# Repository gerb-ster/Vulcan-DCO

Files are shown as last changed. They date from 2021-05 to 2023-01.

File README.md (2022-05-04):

# Vulcan DCO

## Status: (Almost) finished*

- done: draw first schematic
- done: breadboard and test
- done: board design
- done: design frontpanel
- done: order PCB and build prototype

*) I only need to finish building a proper faceplate; otherwise this project is done.

## Theory

This DCO module is based on an article written by Alethea Flowers about the Roland Juno series. 
The idea behind this specific DCO is that a (analog) ramp generator is being controlled by 
a (digital) microcontroller. A clock signal comming from the micro controller will control the 
frequency of the ramp generator. The nature of this perticular circuit is such, that an increase of 
the frequency means an decrease of the output amplitude of the generated waveform. To counter 
this effect, a DAC is used to compensate the input voltage. If you want more in-depth information
about this, I would highly recommend you read the above mentioned article. A link is provided below.

## Requirements

For this module I aimed at the following specs

- 1v/oct control voltage (-3v to +5v)
- 8 octave range (A0 to A8)
- Triangle, Saw, Sine, Pulse, Square and Sub-Square outputs
- 1k output impedance
- 10 Vpp around 0 volts output
- PWM control for the Pulse output

## Internals

Since this systems requires a micro controller to control it, I've choosen the ATTiny84 running at 20Mhz
from Microchip for this purpose. It has all peripherals (ADC, timers, SPI) on board and it has a relative
small footprint. For the DAC I've choosen a MCP4921 which is connected to the ATTiny through SPI. To generate
a stabel reference voltage, a TL431 shunt voltage regulator is used. For all other tasks, scaling and shifting
the CV and wave generators, TL082/TL084 op-amps are used.

## General Workings

The control voltage comming in is scaled down by 2 and shifted down to 0v to translate the -3v/+5v into 0v/+4v.
Diode clamps are used to make sure the signal doesn't go below 0v or +5v. This signal is then fed to the 10bit 
ADC of the microchip, which has a AREF of 4v, so 0v has a value of 0, while 4v will have a value of 1024. This 
value is then used to determine the input voltage of the ramp genator using the DAC and the clock signal which 
controls it's frequency. The generated ramp wave is then used to generate the sine, triangle, and pulse waves
using several wave shapers. The square and sub square waves are taken directly from the clock signal comming 
from the microchip.

A simple block diagram outlining the inner workings

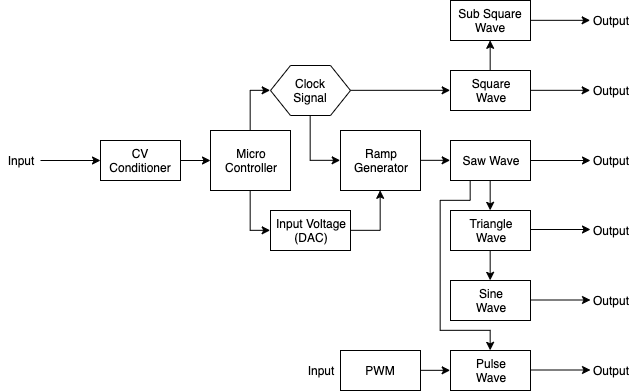
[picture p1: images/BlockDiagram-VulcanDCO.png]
Block Diagram


## The Microchip

The most interresting part of this system is the microchip controlling the ramp generator. All other parts are
more or less standard building blocks which you will find in various other VCO schematics. As mentioned above,
the microchip uses it's ADC to convert the incoming control voltage to a 10bit value which is used to control
the ramp generator. To do this, every one of these 1024 values needs to be translated to a certain clock 
frequency and an input voltage. Since this is not a linear scale, some math has to be done. I've tried to break
it down in the following sections:

### CV to Frequencies

I've used this table to translate the control voltages to frequencies. I've also added the CV value after shifting
and scaling and the correspondending ADC values. 

| CV | Norm. CV | Note | Hz | ADC Value  |
|---|---|---|---|---|
| -3v | 0.0v | A0 | 27.5 Hz | 0
| -2v | 0.5v | A1 | 55 Hz | 127
| -1v | 1.0v | A2 |  110 Hz | 255
| 0v | 1.5v | A3 |  220 Hz | 383
| 1v | 2.0v | A4 |  440 Hz | 511
| 2v | 2.5v | A5 |  880 Hz | 639
| 3v | 3.0v | A6 | 1760 Hz | 767
| 4v | 3.5v | A7 | 3520 Hz | 895
| 5v | 4.0v | A8 | 7040 Hz | 1023

The formula used here is:

```
frequency = (2 ^ (2 * normalized_control_voltage)) * 27.5
```

### Setting the Clock Frequency

For the clock signal I've used one of the Timers (timer1) of the ATTiny84. It is set up in such a
way that it generates a square wave at pin 7 with a frequency set by manipulating a compare mode
value. If you want more specifics and want to know what registers are set, please check out the 
source code, comments are provided. For every duty cycle of the squeare wave we need 2 pulses, one
to turn the output high, one to turn it low. This formula is used ('F_CPU' is the clock speed of the
CPU (20Mhz) and 'current_prescaler' is the prescaler used in this timer(8)):

```
timer_value = (F_CPU / current_prescaler) / (frequency * 2)
```

For more information about using the timer of an ATTiny84, links are provided below.

### Input Voltage Compensation

As mentioned above, we need to compensate the input voltage of the ramp generator to make sure the
amplitude of the output remains the same. To do this we use a DAC. The DAC generates a voltage between
0v and 4v, using a 12bit value (0-4096). For this we also use the 4.00v shunt voltage regulator as a
voltage reference. This voltage is then inverted and multiplied with a factor 3 to cover a range of
0v to -12v. This way the ramp generator will output a 12vpp ramp between 0v and 12v.

The formula to transform a frequency to the appropriate DAC voltage can be found in the article by
Alethea Flowers, she explains it in much better details then I can do, so if you're interested in that,
the link can be found below.

```
C = 1nF
R = 200k Ohm
Vout = +12v

time = 1 / frequency
Vin = -(C * R * Vout) / time
```

#### However... 

After a lot of testing and doing measurements I found out that this formula works, but it kind of 
starts failing for the lower frequencies. Below 300Hz you will need a higher input voltage to get a consistent
output voltage. To make it easier for myself I've picked an 10Vpp instead of 12Vpp for my measurements. I've
plotted these numbers on a graph and it turned out pretty linear so when i used the formula which came out
this graph, the low end output voltage are much more consistent.

I'm not a mathematician so why or how this formula works, i don't know :-)

```
Vin = (0.697151065 * frequency) + 40.82
```

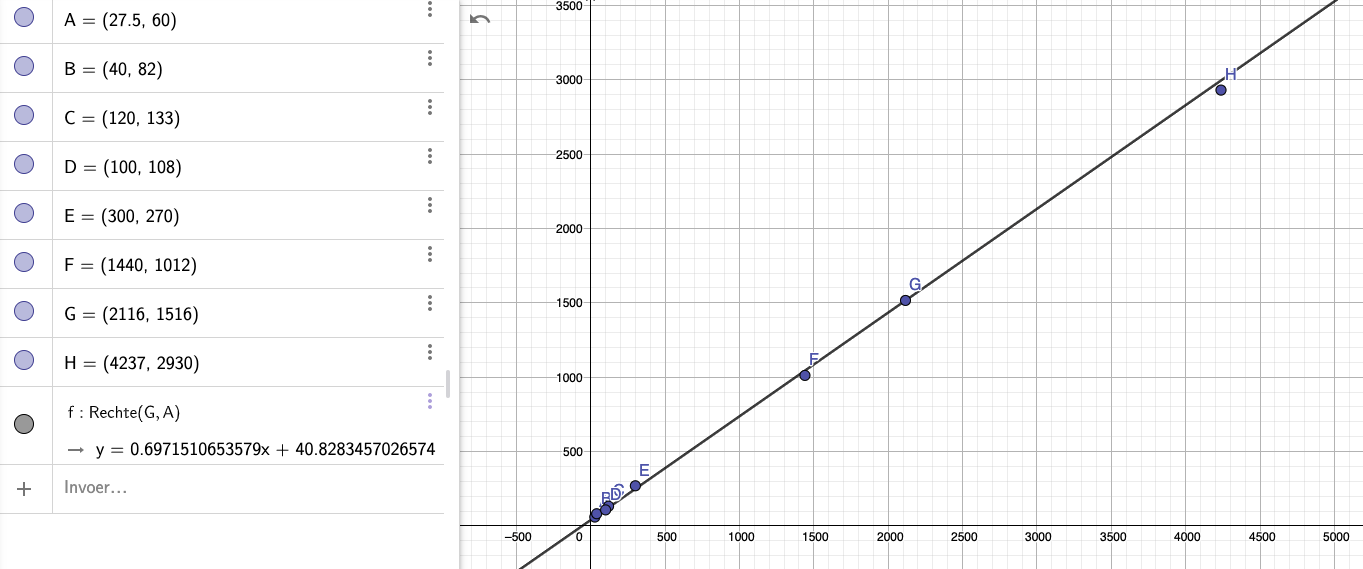
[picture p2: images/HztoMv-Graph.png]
Hz to mV Graph


### Lookup Tables

If you look through the source code you won't find any of the above decribed formulas. This is because 
I've used 2 lookup tables to speed things up. Although the ATTiny84 could do the Math involved, this is 
not really necessary. Every one of the 1024 values coming from ADC will translate into a 'fixed' timer and 
DAC value. So there is no real need to calculate these values on the fly. These lookup tables are basically 
2 giant arrays, 1024 elements in size, which contain all pre-calculated values. These arrays are stored in
the Flash memory of the ATTiny since the normal RAM is to small. 

In the 'utils' folder you can find the ```generator.php``` file which is used to generate those tables and 
code. I've choosen to use PHP for this, because this is my 'native' language :-).

## Waveshapers

The Square and Sub-Square outputs are derived directly from the Clock signal using various op-amps and a 
CD4013 Dual Flip-Flop IC. This schematic is taken from a design for the 'making music with a 566' by
Thomas Henry. Next, the Saw Wave coming out of the Ramp generator is used to shape it into a Triangle wave.
This Triangle wave is then used to generate a Sine wave. The Saw wave is also used to create a Pulse wave.
There is a CV input and pot to control the Pulse Width Modulation. For these wave shapers I've used 
designs from Thomas Henry, Ray Wilson and Yves Usson (YUSynth). Links are found below.

## Calibration

There are 2 trimmerpots that need to be set, in order to calibrate the Ramp Generator Core. 

CV_OFFSET => -1.5v  
VREF_SET => 4.00v  

## Links

<https://blog.thea.codes/the-design-of-the-juno-dco/>  
<https://www.geogebra.org/graphing/mfdyqrfj>  
<https://www.bristolwatch.com/ccs/TL431A.htm>  
<https://github.com/JChristensen/tinySPI>  
<https://github.com/MetreIdeas/ATtinyx4A_ADC_Example>  
<https://eleccelerator.com/avr-timer-calculator/>  
<https://maxembedded.wordpress.com/2011/06/28/avr-timers-timer1/>  
<https://www.nongnu.org/avr-libc/user-manual/pgmspace.html>  
<https://www.arduino.cc/reference/tr/language/variables/utilities/progmem/>  
<https://www.birthofasynth.com/Thomas_Henry/Pages/VCO-1.html>  
<https://yusynth.net/Modular/EN/VCO/index.html>

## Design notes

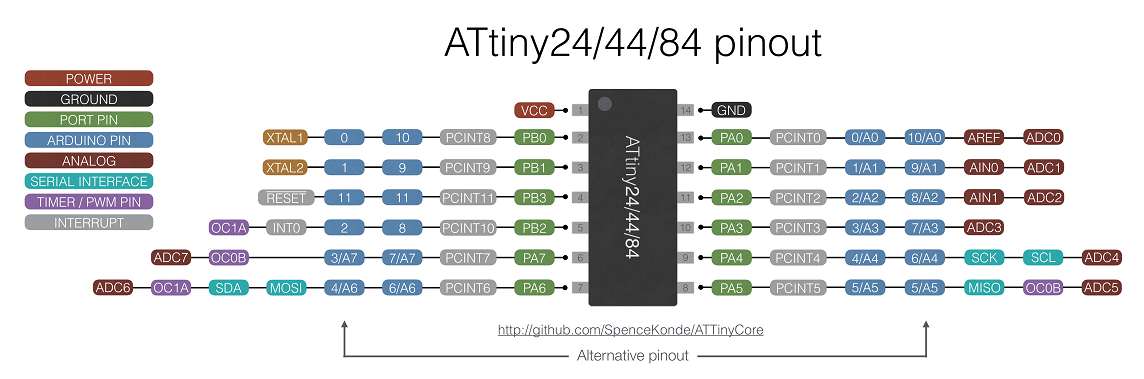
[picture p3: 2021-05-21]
images/attiny-pinout-diagram.png

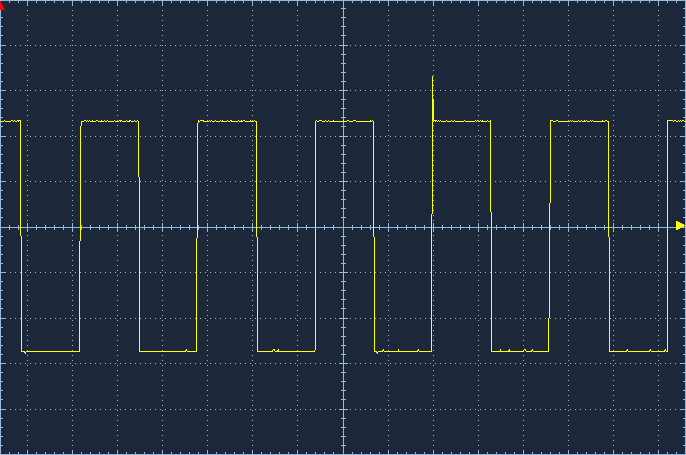
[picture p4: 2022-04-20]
images/square.png

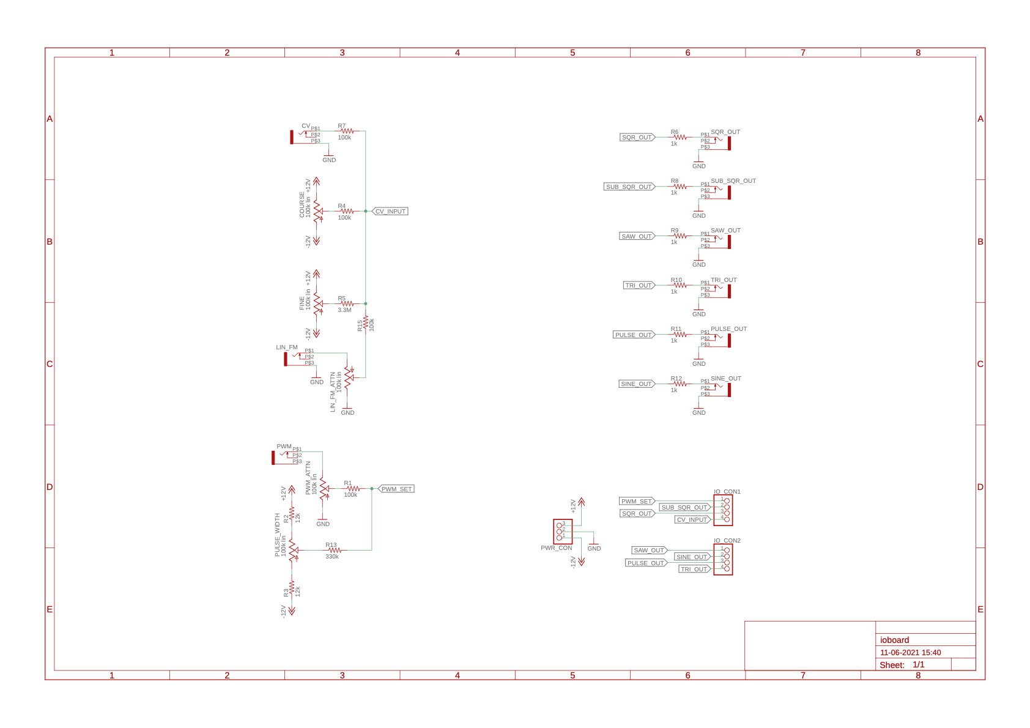
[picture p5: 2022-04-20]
images/Vulcan-DCO-ioboard.png

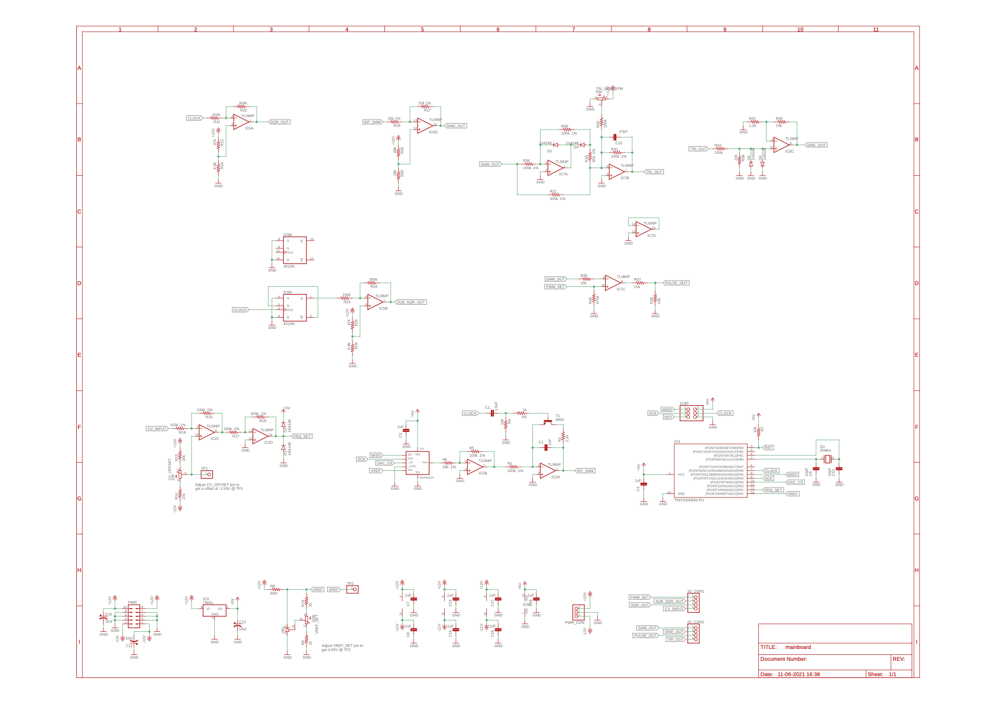
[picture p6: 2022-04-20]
images/Vulcan-DCO-mainboard.png

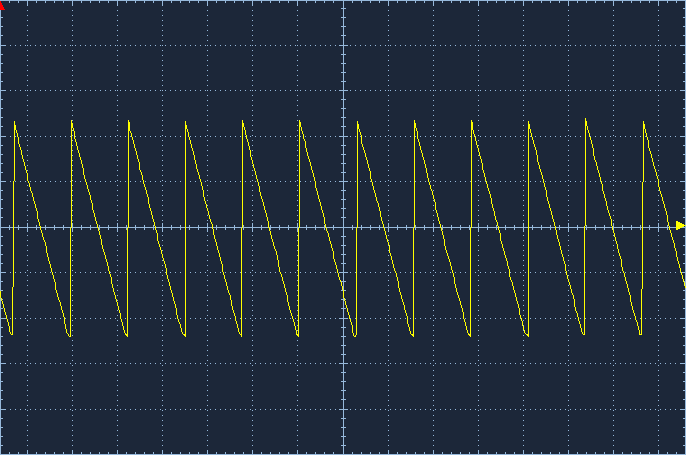
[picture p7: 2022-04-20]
images/saw.png

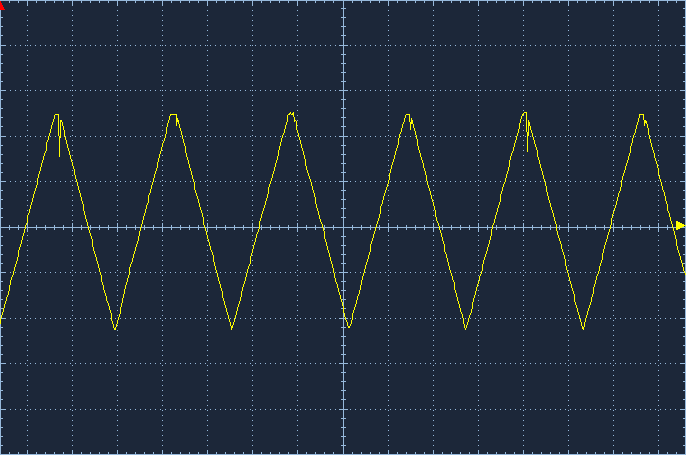
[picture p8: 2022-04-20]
images/triangle.bmp

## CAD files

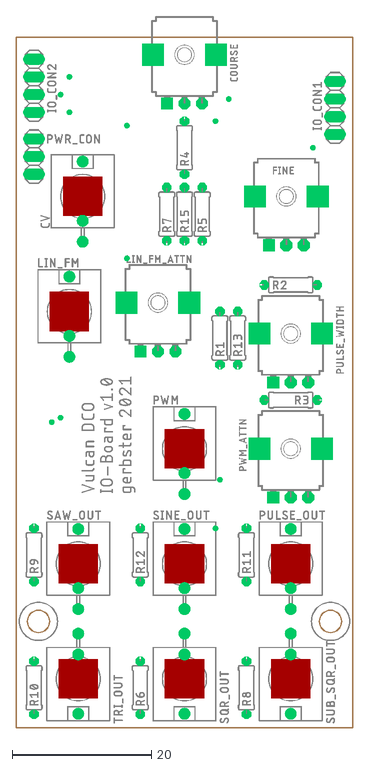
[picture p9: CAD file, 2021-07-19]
faceplates/ioboard.dxf
48.3 x 102.0

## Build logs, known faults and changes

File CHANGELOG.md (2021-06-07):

# Changelog

All notable changes to this project will be documented in this file.

The format is based on [Keep a Changelog](https://keepachangelog.com/en/1.0.0/),
and this project adheres to [Semantic Versioning](https://semver.org/spec/v2.0.0.html).

## [1.0.0] - 2021-21-05

### Added

- Inintial repo setup
- First version of firmware added

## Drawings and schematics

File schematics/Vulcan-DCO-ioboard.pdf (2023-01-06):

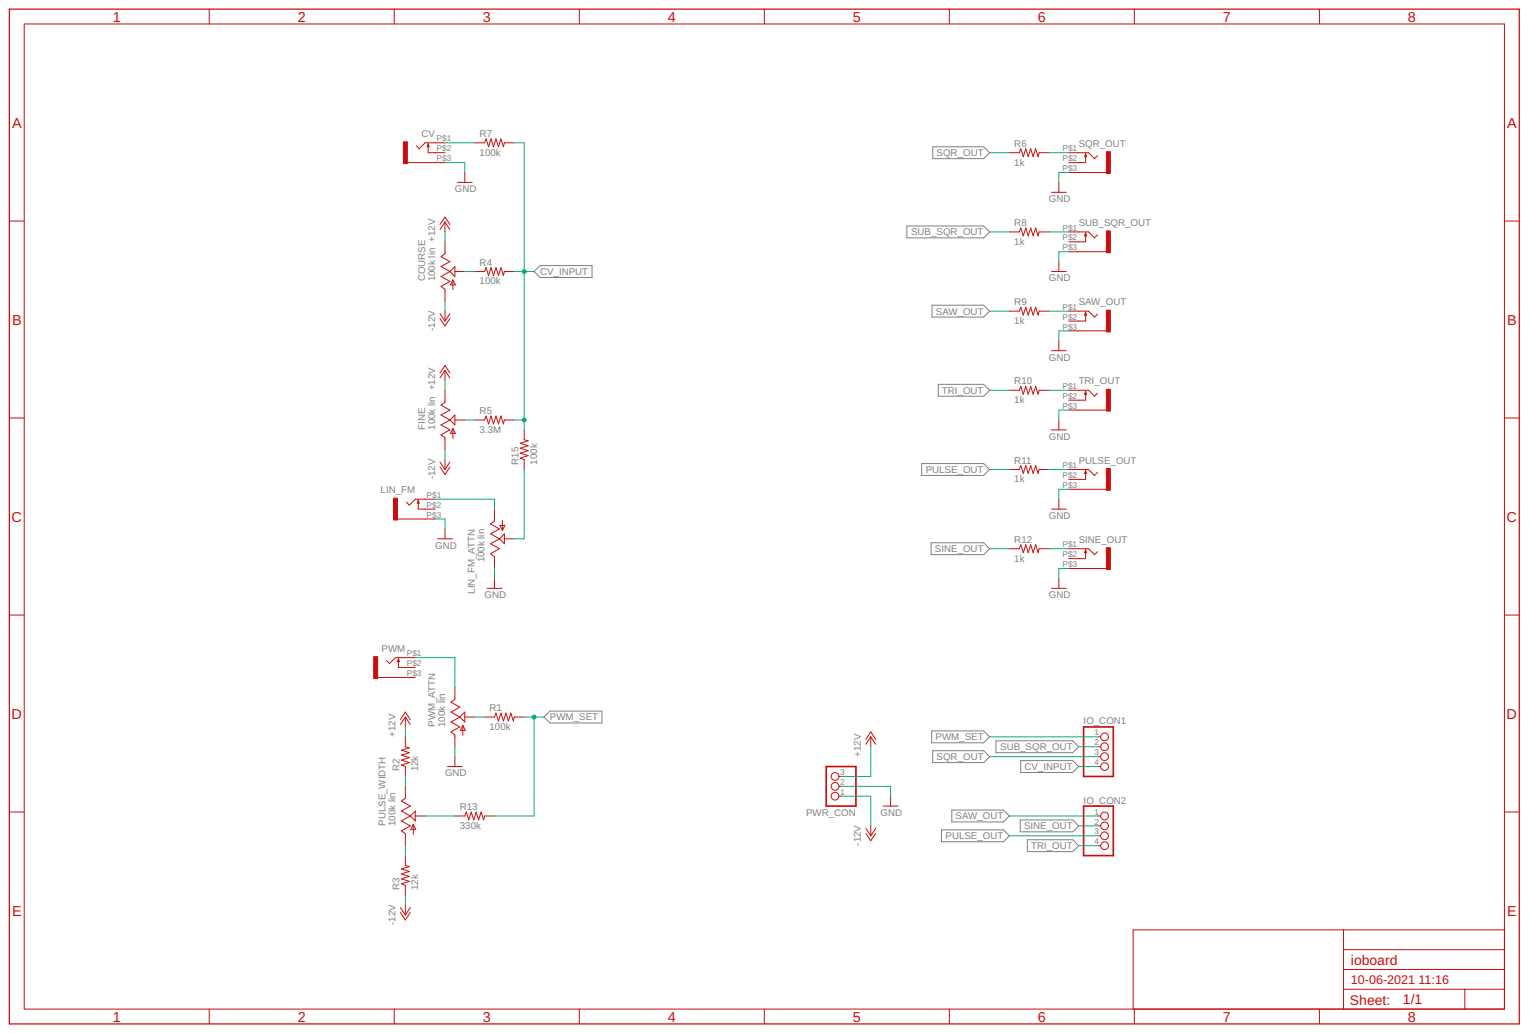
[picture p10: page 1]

+12V -12V GND 100k lin 100k lin 100k lin +12V -12V -12V +12V 100k 3.3M 1k GND 100k 1k1k1k1k GND GND GND GND GND GND +12V -12V 330k 100k lin GND GND 100k 100k lin GND 100k 12k 12k 1k 123 PWR_CON COURSE FINE PULSE_WIDTH R4 R5 R6 P$3 P$1 P$2 CV P$3 P$1 P$2 PWM P$3 P$1 P$2SQR_OUT P$3 P$1 P$2SUB_SQR_OUT P$3 P$1 P$2SAW_OUT P$3 P$1 P$2TRI_OUT P$3 P$1 P$2PULSE_OUT P$3 P$1 P$2SINE_OUT R7 R8 R9 R10 R12 R13 P$3 P$1 P$2 LIN_FM LIN_FM_ATTN R15 PWM_ATTN R1 R2 R3 R11 1234 IO_CON2 1234 IO_CON1 CV_INPUT CV_INPUT SQR_OUT SQR_OUT SUB_SQR_OUT SUB_SQR_OUT SAW_OUT SAW_OUT TRI_OUT TRI_OUT PULSE_OUT PULSE_OUT SINE_OUT SINE_OUT PWM_SET PWM_SET Sheet: ABCDE 1 2 3 4 5 6 7 8 ABCDE 1 2 3 4 5 6 7 8 ioboard 10-06-2021 11:16 1/1

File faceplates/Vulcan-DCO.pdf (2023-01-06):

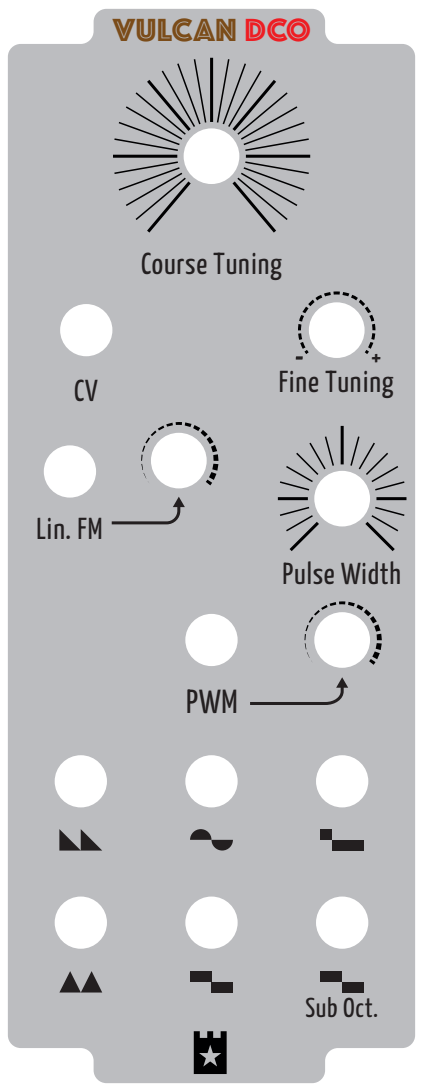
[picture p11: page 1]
Course Tuning; Lin. FM; Pulse Width; PWM; VULCAN DCO; Sub Oct.

Fine Tuning CV

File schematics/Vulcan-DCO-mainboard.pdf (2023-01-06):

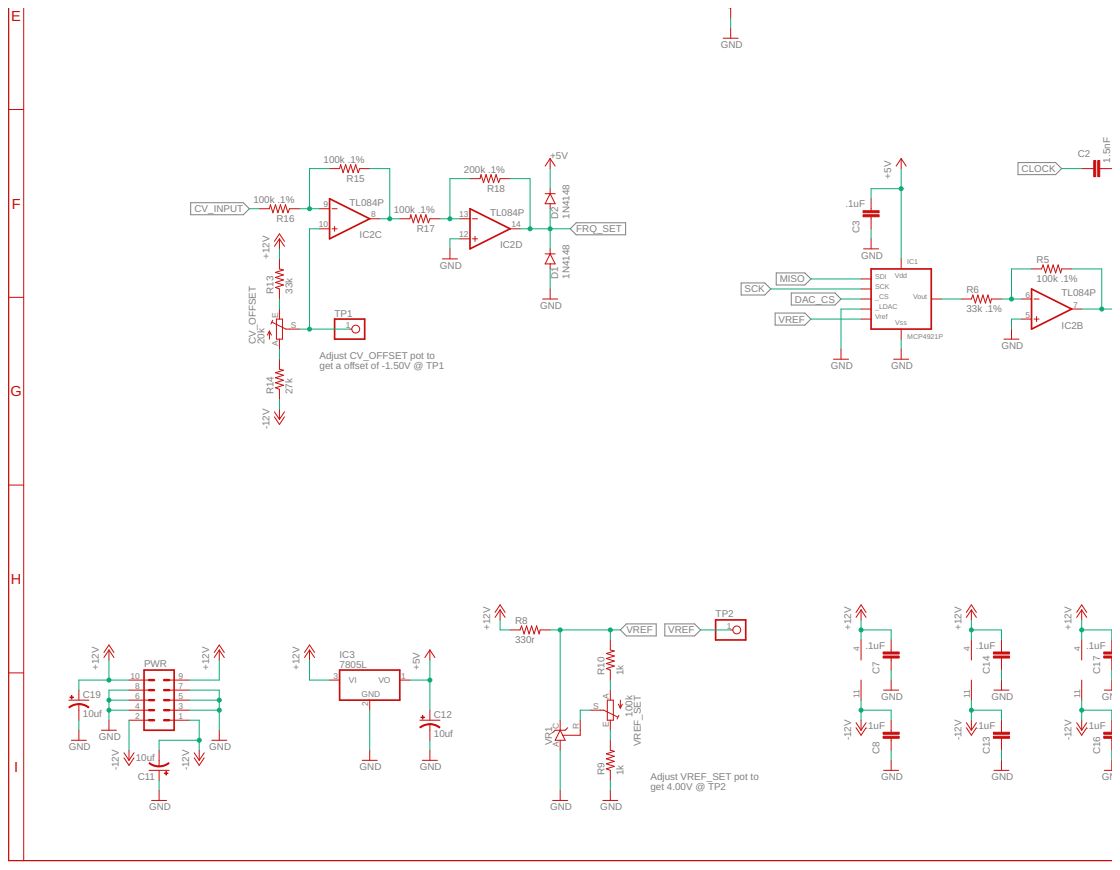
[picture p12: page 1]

Vdd Vss Vout Vref SCK

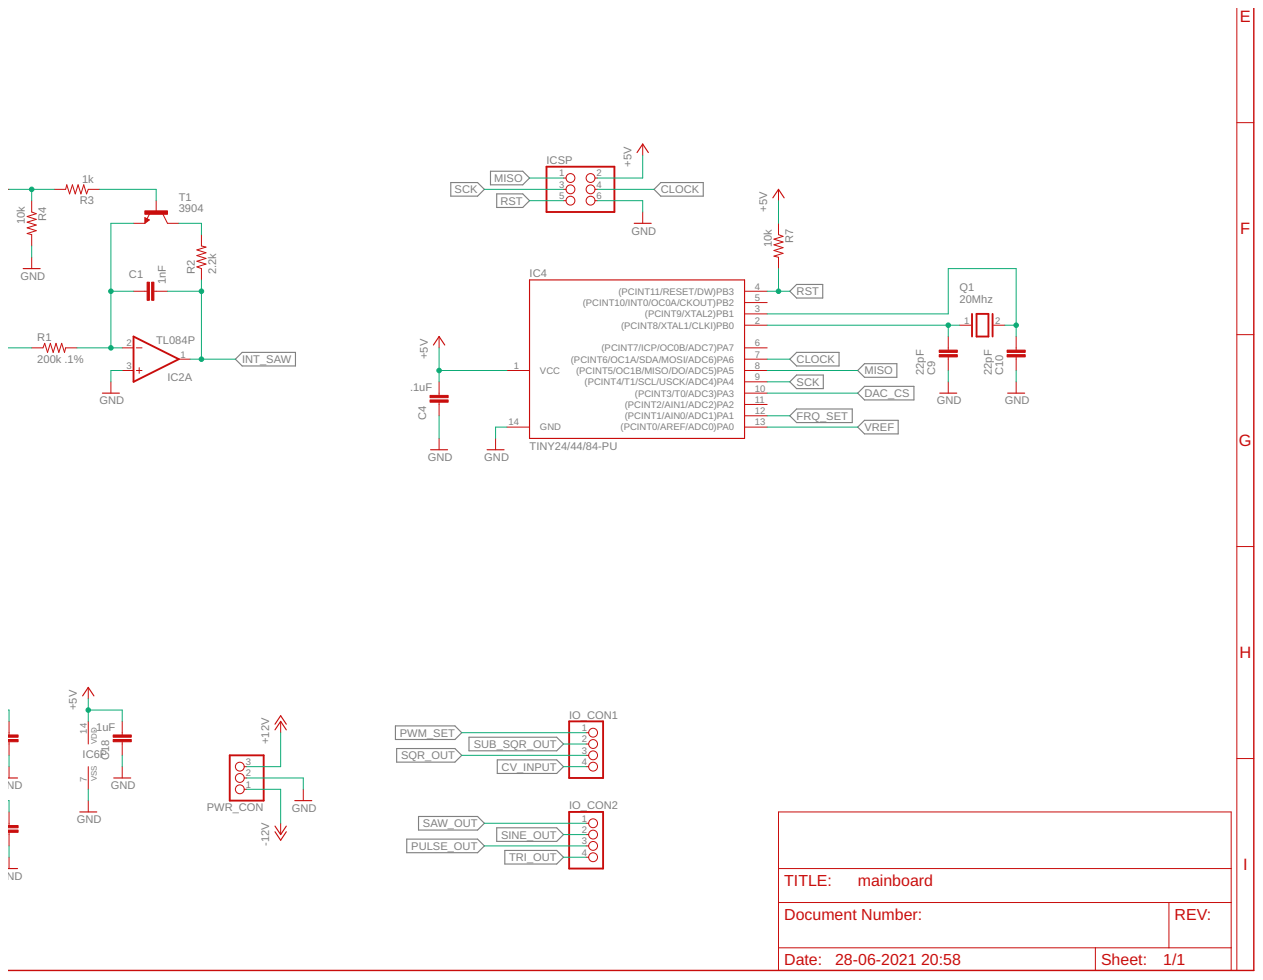
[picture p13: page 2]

Document Number: | REV:

Date: 28-06-2021 20:58 | Sheet: 1/1

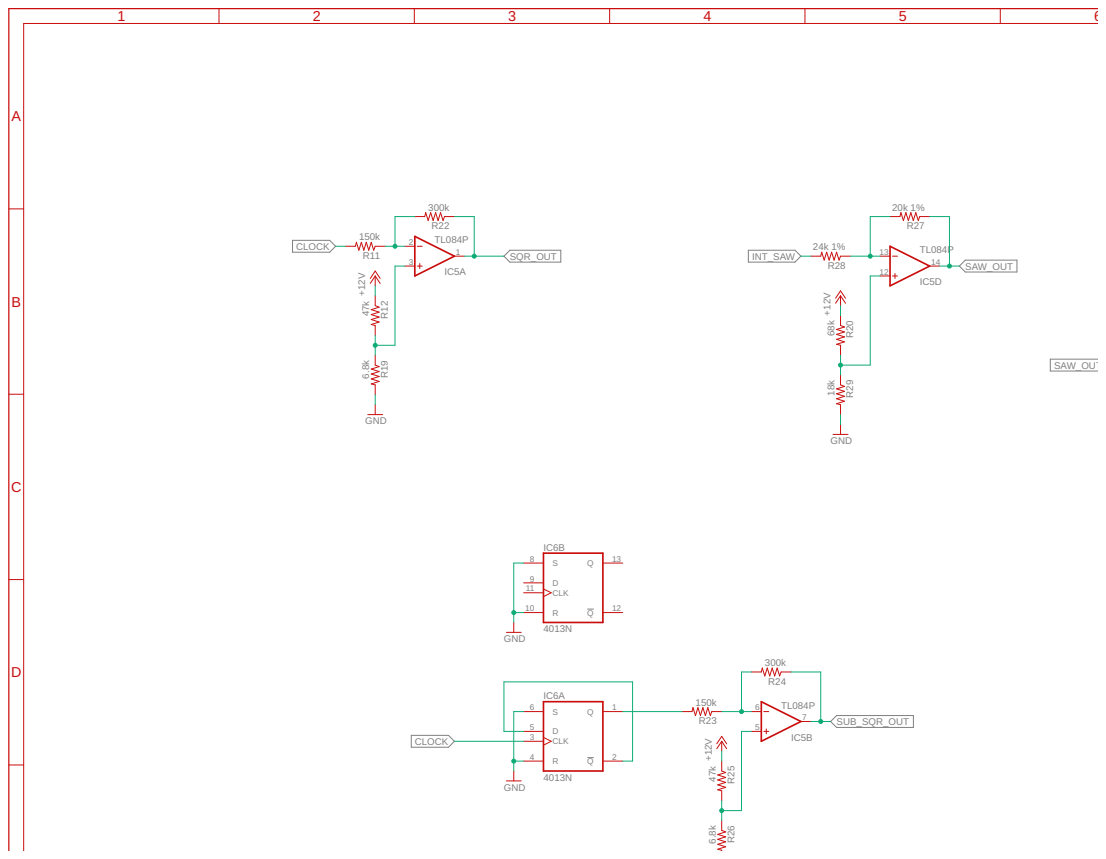
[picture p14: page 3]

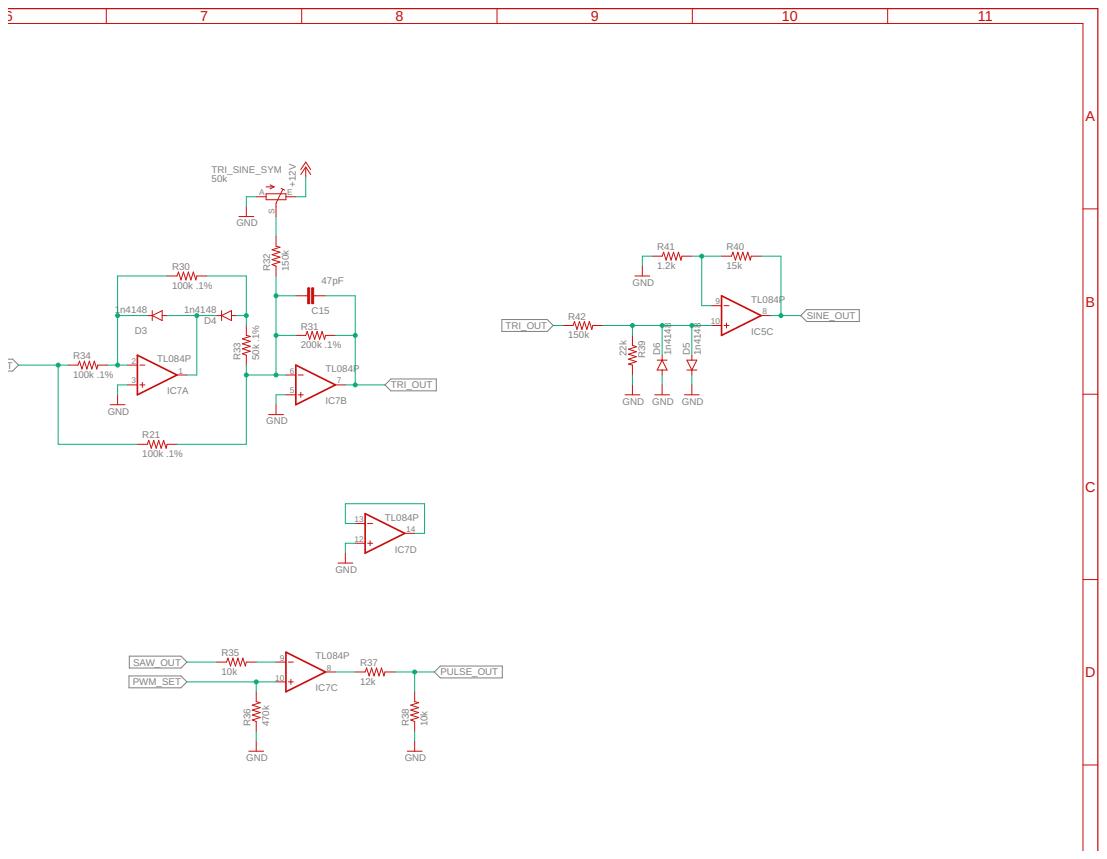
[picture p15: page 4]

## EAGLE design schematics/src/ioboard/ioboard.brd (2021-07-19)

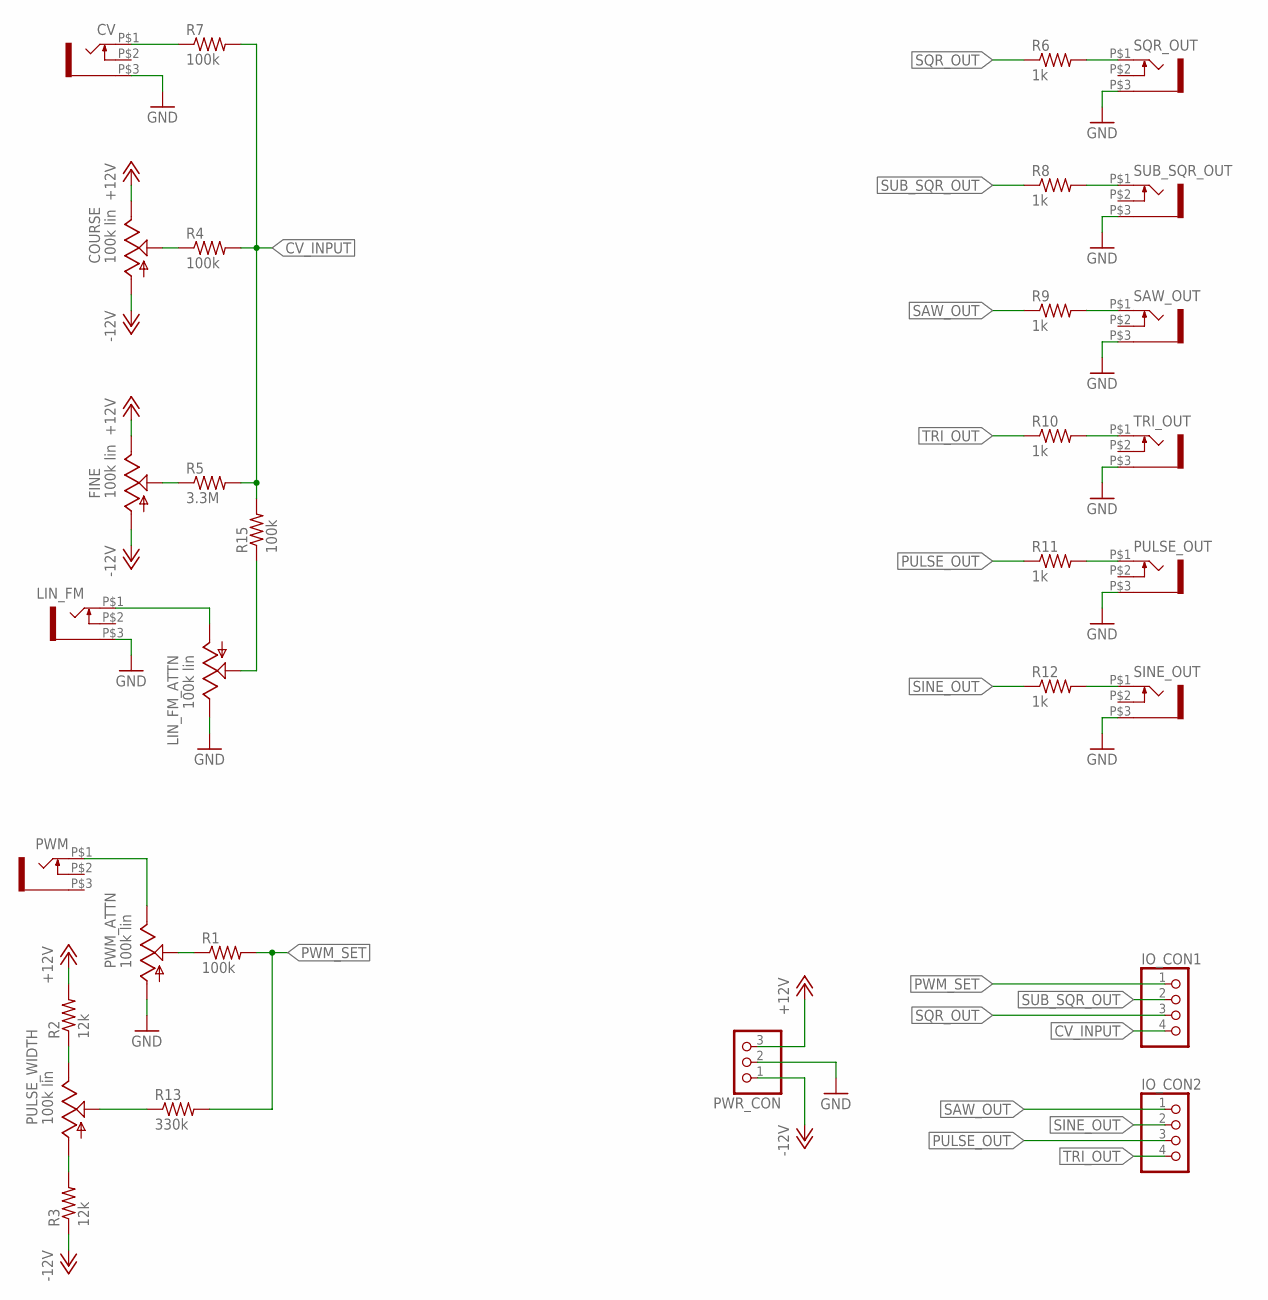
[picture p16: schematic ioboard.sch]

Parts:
COURSE: 100k lin; EVUF
CV: WQP-PJ301M-12_JACK
FINE: 100k lin; EVUF
IO_CON1, IO_CON2: PINHD-1X4; 1X04
LIN_FM: WQP-PJ301M-12_JACK
LIN_FM_ATTN: 100k lin; EVUF
PULSE_OUT: WQP-PJ301M-12_JACK
PULSE_WIDTH: 100k lin; EVUF
PWM: WQP-PJ301M-12_JACK
PWM_ATTN: 100k lin; EVUF
PWR_CON: PINHD-1X3; 1X03
R1, R4, R7, R15: 100k; 0207/7
R2, R3: 12k; 0207/7
R5: 3.3M; 0207/7
R6, R8, R9, R10, R11, R12: 1k; 0207/7
R13: 330k; 0207/7
SAW_OUT: WQP-PJ301M-12_JACK
SINE_OUT: WQP-PJ301M-12_JACK
SQR_OUT: WQP-PJ301M-12_JACK
SUB_SQR_OUT: WQP-PJ301M-12_JACK
TRI_OUT: WQP-PJ301M-12_JACK

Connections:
+12V: COURSE.3 (E), FINE.3 (E), PWR_CON.3, R2.2
-12V: COURSE.1 (A), FINE.1 (A), PWR_CON.1, R3.1
CV_INPUT: IO_CON1.4, R4.2, R5.2, R7.2, R15.2
GND: CV.P$3 (1), LIN_FM.P$3 (1), LIN_FM_ATTN.3 (E), PULSE_OUT.P$3 (1), PWM_ATTN.1 (A), PWR_CON.2, SAW_OUT.P$3 (1), SINE_OUT.P$3 (1), SQR_OUT.P$3 (1), SUB_SQR_OUT.P$3 (1), TRI_OUT.P$3 (1)
unnamed: COURSE.2 (S), R4.1
unnamed: FINE.2 (S), R5.1
unnamed: PULSE_WIDTH.3 (E), R2.1
unnamed: CV.P$1 (2), R7.1
unnamed: R6.2, SQR_OUT.P$1 (2)
unnamed: R8.2, SUB_SQR_OUT.P$1 (2)
unnamed: R9.2, SAW_OUT.P$1 (2)
unnamed: R10.2, TRI_OUT.P$1 (2)
unnamed: PULSE_WIDTH.1 (A), R3.2
unnamed: R12.2, SINE_OUT.P$1 (2)
unnamed: PULSE_WIDTH.2 (S), R13.1
unnamed: PWM.P$1 (2), PWM_ATTN.3 (E)
unnamed: PULSE_OUT.P$1 (2), R11.2
unnamed: PWM_ATTN.2 (S), R1.1
unnamed: LIN_FM.P$1 (2), LIN_FM_ATTN.1 (A)
unnamed: LIN_FM_ATTN.2 (S), R15.1
PULSE_OUT: IO_CON2.3, R11.1
PWM_SET: IO_CON1.1, R1.2, R13.2
SAW_OUT: IO_CON2.1, R9.1
SINE_OUT: IO_CON2.2, R12.1
SQR_OUT: IO_CON1.3, R6.1
SUB_SQR_OUT: IO_CON1.2, R8.1
TRI_OUT: IO_CON2.4, R10.1

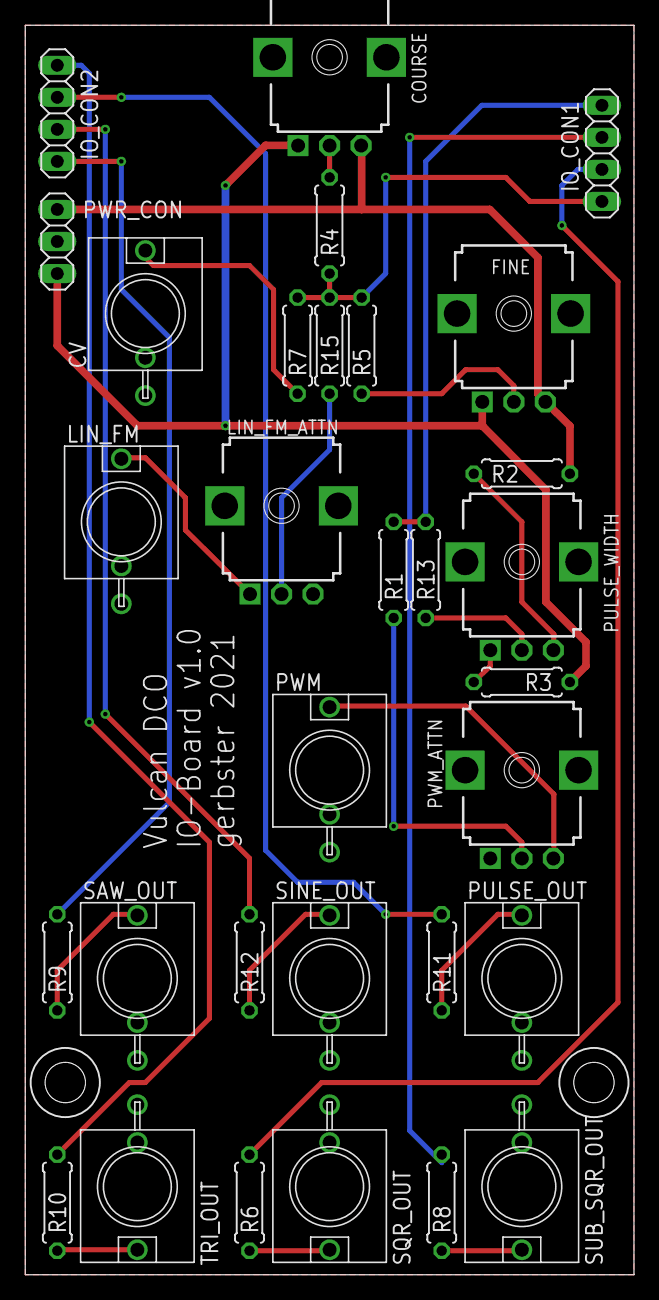
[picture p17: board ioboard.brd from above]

Board: 2 copper layers, 48.3 x 99.1 mm, 31 parts (0 on the bottom side), 27 nets.

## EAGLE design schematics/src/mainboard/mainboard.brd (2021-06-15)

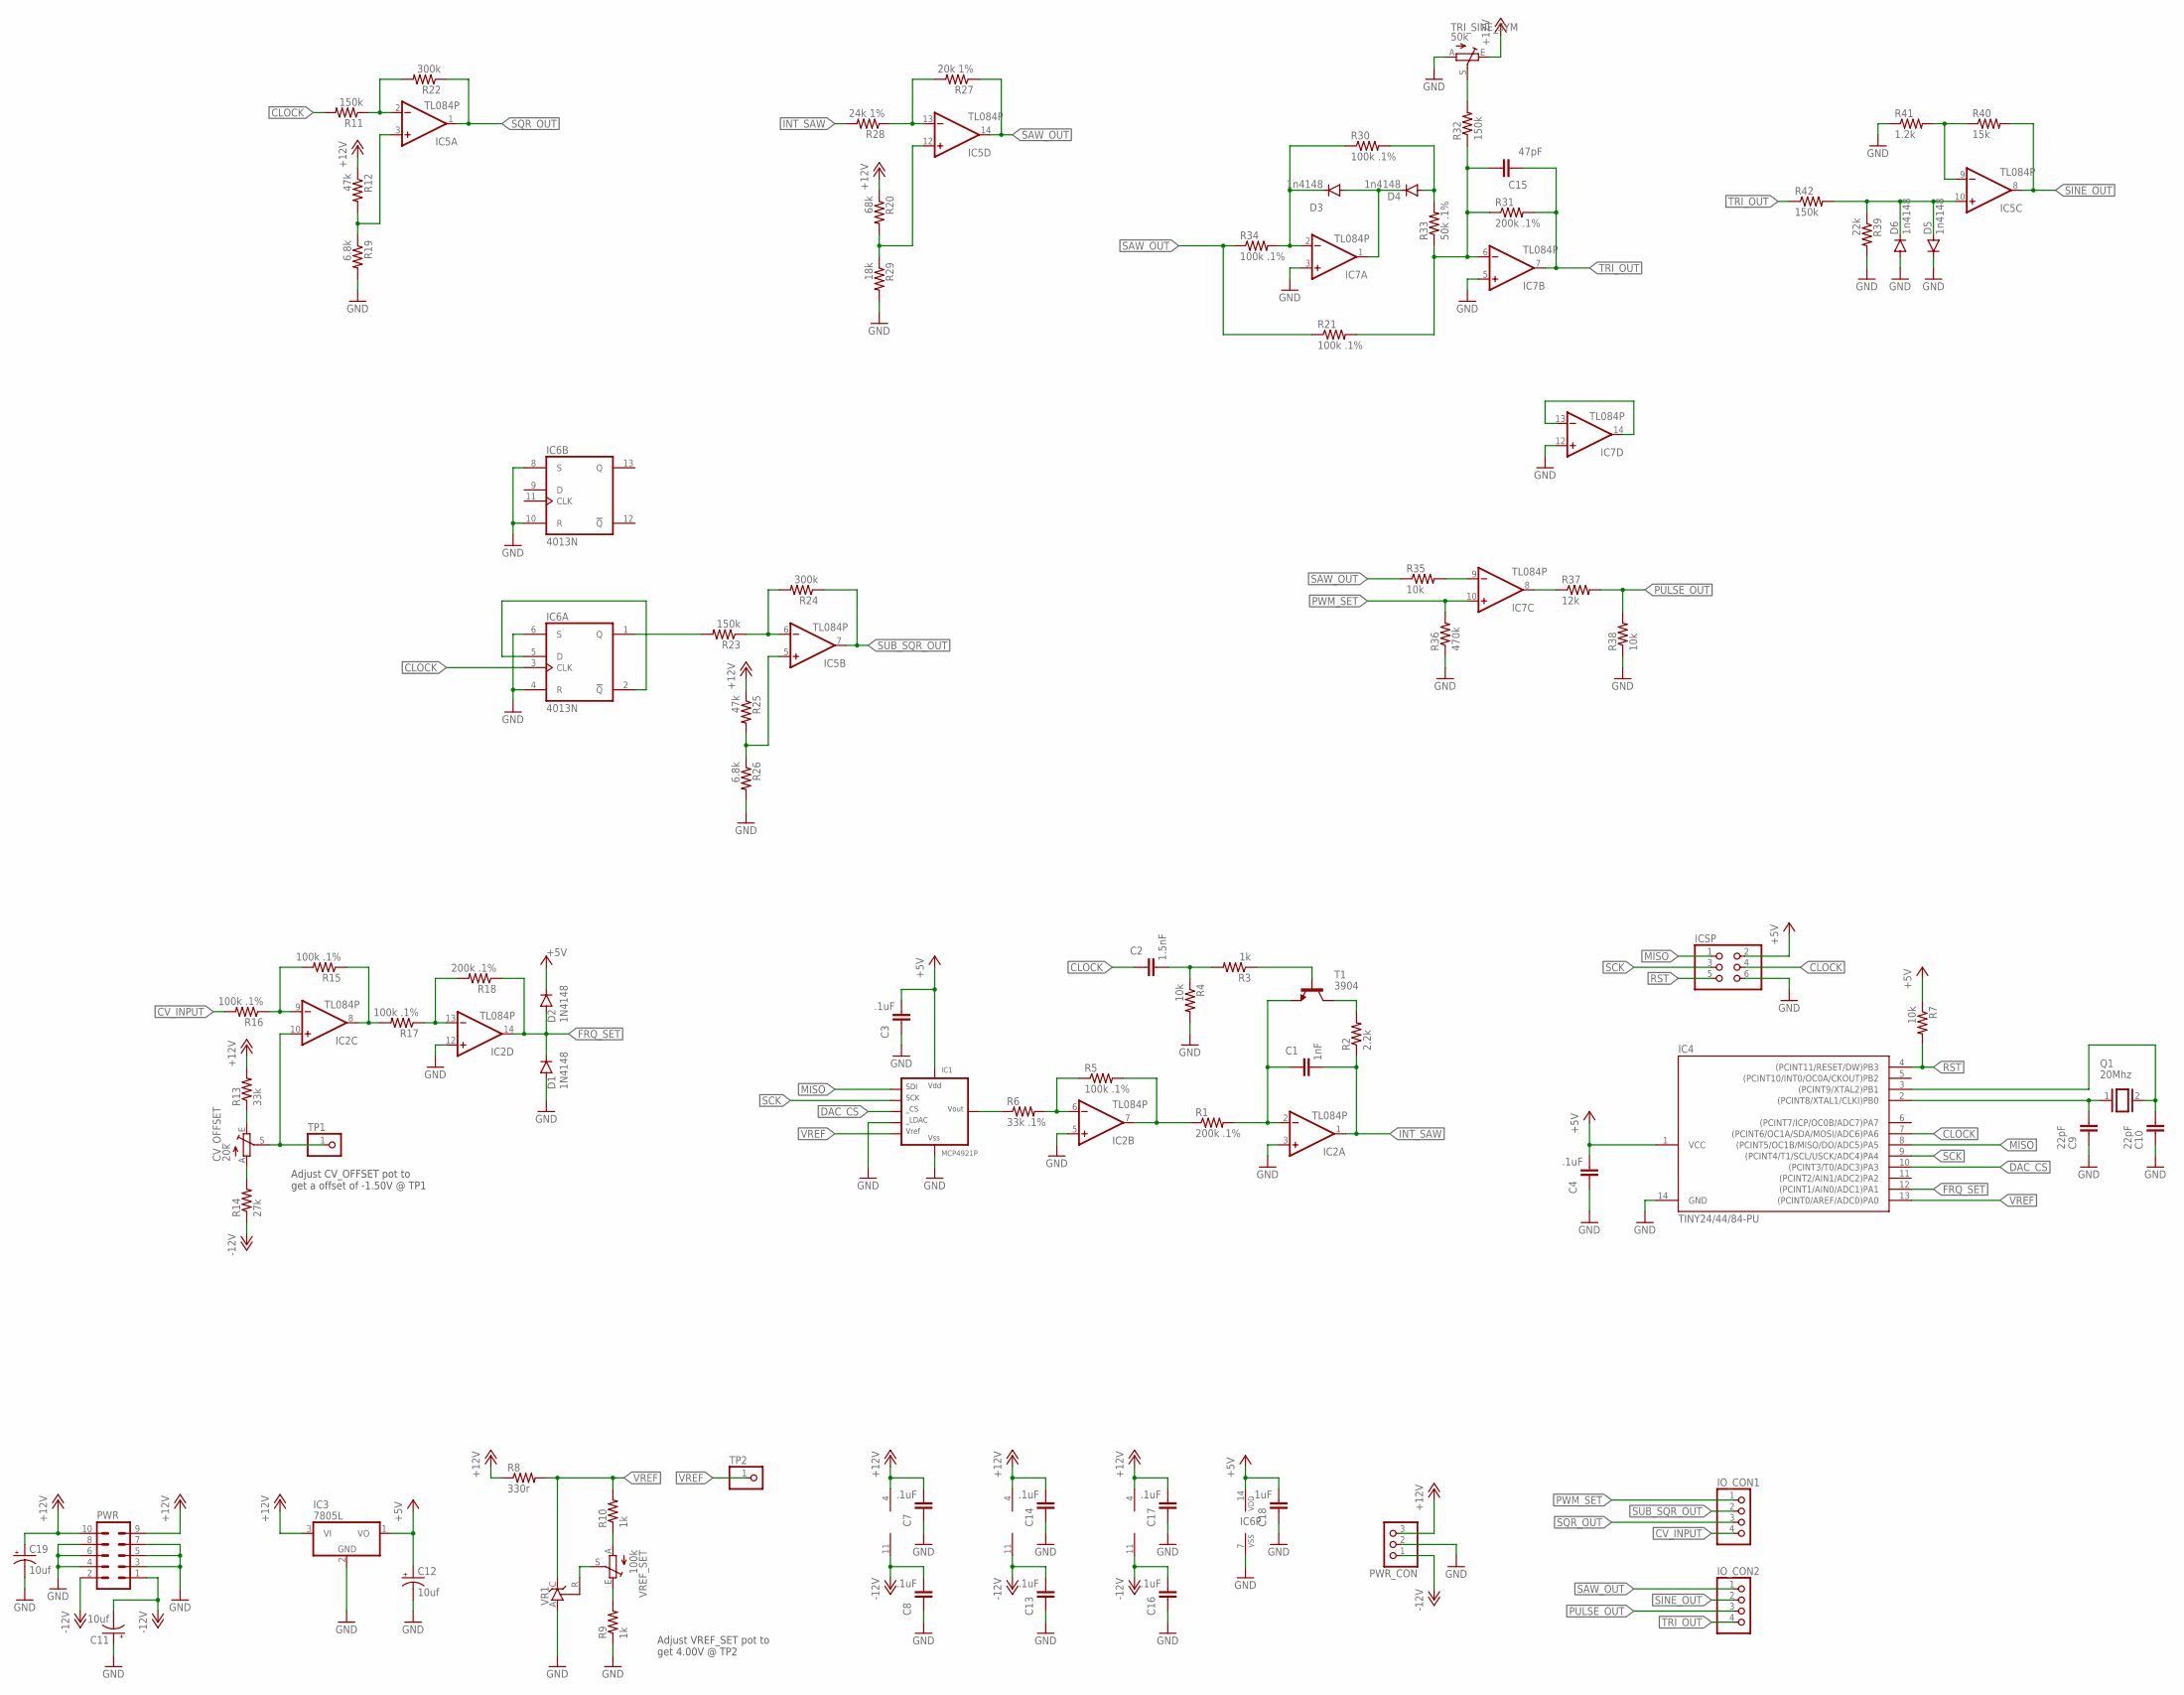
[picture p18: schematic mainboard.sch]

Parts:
C1: 1nF; C050-025X075
C2: 1.5nF; C050-024X044
C3, C4, C7, C8, C13, C14, C16, C17, C18: .1uF; C050-024X044
C9, C10: 22pF; C050-024X044
C11, C12, C19: 10uf; E2,5-5
C15: 47pF; C050-024X044
CV_OFFSET: 20k; S64YW
D1, D2: 1N4148; DO35-7
D3, D4, D5, D6: 1n4148; DO35-7
IC1: MCP4921P; DIL8
IC2, IC5, IC7: TL084P; DIL14
IC3: 7805L; TO92
IC4: TINY24/44/84-PU; DIL14
IC6: 4013N; DIL14
ICSP: PINHD-2X3; 2X03
IO_CON1, IO_CON2: PINHD-1X4; 1X04
PWR: ML10
PWR_CON: PINHD-1X3; 1X03
Q1: 20Mhz; QS
R1, R18, R31: 200k .1%; 0207/7
R2: 2.2k; 0207/7
R3, R9, R10: 1k; 0207/7
R4, R7, R35, R38: 10k; 0207/7
R5, R15, R16, R17, R21, R30, R34: 100k .1%; 0207/7
R6: 33k .1%; 0207/7
R8: 330r; 0207/7
R11, R23, R32, R42: 150k; 0207/7
R12, R25: 47k; 0207/7
R13: 33k; 0207/7
R14: 27k; 0207/7
R19, R26: 6.8k; 0207/7
R20: 68k; 0207/7
R22, R24: 300k; 0207/7
R27: 20k 1%; 0207/7
R28: 24k 1%; 0207/7
R29: 18k; 0207/7
R33: 50k .1%; 0207/7
R36: 470k; 0207/7
R37: 12k; 0207/7
R39: 22k; 0207/7
R40: 15k; 0207/7
R41: 1.2k; 0207/7
T1: 3904; TO92-EBC
TP1, TP2: PINHD-1X1; 1X01
TRI_SINE_SYM: 50k; S64YW
VR1: TL431CLP; TO92-CLP
VREF_SET: 100k; S64YW

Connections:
+5V: C3.2, C4.2, C12.+, C18.2, D2.C, IC1.1 (VDD), IC3.1 (VO), IC4.1 (VCC), IC6.14 (VDD), ICSP.2, R7.1
+12V: C7.2, C14.2, C17.2, C19.+, IC2.4 (V+), IC3.3 (VI), IC5.4 (V+), IC7.4 (V+), PWR.9, PWR.10, PWR_CON.3, R8.1, R12.1, R13.2, R20.1, R25.1, TRI_SINE_SYM.E
-12V: C8.2, C11.-, C13.2, C16.2, IC2.11 (V-), IC5.11 (V-), IC7.11 (V-), PWR.1, PWR.2, PWR_CON.1, R14.1
CLOCK: C2.1, IC4.7 ((PCINT6/OC1A/SDA/MOSI/ADC6)PA6), IC6.3 (CLK), ICSP.4, R11.2
CV_INPUT: IO_CON1.4, R16.2
DAC_CS: IC1.2 (CS), IC4.10 ((PCINT3/T0/ADC3)PA3)
FRQ_SET: D1.C, D2.A, IC2.14 (OUT), IC4.12 ((PCINT1/AIN0/ADC1)PA1), R18.1
GND: C3.1, C4.1, C7.1, C8.1, C9.1, C10.1, C11.+, C12.-, C13.1, C14.1, C16.1, C17.1, C18.1, C19.-, D1.A, D5.C, D6.A, IC1.5 (LDAC), IC1.7 (VSS), IC2.3 (+IN), IC2.5 (+IN), IC2.12 (+IN), IC3.2 (GND), IC4.14 (GND), IC6.4 (R), IC6.6 (S), IC6.7 (VSS), IC6.8 (S), IC6.10 (R), IC7.3 (+IN), IC7.5 (+IN), IC7.12 (+IN), ICSP.6, PWR.3, PWR.4, PWR.5, PWR.6, PWR.7, PWR.8, PWR_CON.2, R4.2, R9.1, R19.2, R26.2, R29.2, R36.1, R38.1, R39.2, R41.1, TRI_SINE_SYM.A, VR1.A
INT_SAW: C1.2, IC2.1 (OUT), R2.1, R28.2
MISO: IC1.4 (SDI), IC4.8 ((PCINT5/OC1B/MISO/DO/ADC5)PA5), ICSP.1
unnamed: C1.1, IC2.2 (-IN), R1.2, T1.E
unnamed: R2.2, T1.C
unnamed: R3.1, T1.B
unnamed: R9.2, VREF_SET.E
unnamed: C2.2, R3.2, R4.1
unnamed: IC2.7 (OUT), R1.1, R5.2
unnamed: C9.2, IC4.2 ((PCINT8/XTAL1/CLKI)PB0), Q1.1
unnamed: IC2.6 (-IN), R5.1, R6.2
unnamed: IC1.8 (VOUT), R6.1
unnamed: IC6.1 (Q), R23.2
unnamed: C10.2, IC4.3 ((PCINT9/XTAL2)PB1), Q1.2
unnamed: R10.1, VREF_SET.A
unnamed: VR1.R, VREF_SET.S
unnamed: CV_OFFSET.A, R14.2
unnamed: CV_OFFSET.E, R13.1
unnamed: CV_OFFSET.S, IC2.10 (+IN), TP1.1
unnamed: IC2.9 (-IN), R15.2, R16.1
unnamed: IC6.2 (!Q), IC6.5 (D)
unnamed: IC2.8 (OUT), R15.1, R17.2
unnamed: IC2.13 (-IN), R17.1, R18.2
unnamed: IC5.6 (-IN), R23.1, R24.2
unnamed: IC5.2 (-IN), R11.1, R22.2
unnamed: IC5.3 (+IN), R12.2, R19.1
unnamed: IC5.5 (+IN), R25.2, R26.1
unnamed: IC5.12 (+IN), R20.2, R29.1
unnamed: IC5.13 (-IN), R27.2, R28.1
unnamed: C15.2, IC7.6 (-IN), R21.2, R31.1, R32.1, R33.1
unnamed: D3.C, IC7.2 (-IN), R30.1, R34.2
unnamed: D3.A, D4.C, IC7.1 (OUT)
unnamed: D4.A, R30.2, R33.2
unnamed: IC7.8 (OUT), R37.1
unnamed: IC7.9 (-IN), R35.2
unnamed: D5.A, D6.C, IC5.10 (+IN), R39.1, R42.2
unnamed: R32.2, TRI_SINE_SYM.S
unnamed: IC7.13 (-IN), IC7.14 (OUT)
unnamed: IC5.9 (-IN), R40.1, R41.2
PULSE_OUT: IO_CON2.3, R37.2, R38.2
PWM_SET: IC7.10 (+IN), IO_CON1.1, R36.2
RST: IC4.4 ((PCINT11/RESET/DW)PB3), ICSP.5, R7.2
SAW_OUT: IC5.14 (OUT), IO_CON2.1, R21.1, R27.1, R34.1, R35.1
SCK: IC1.3 (SCK), IC4.9 ((PCINT4/T1/SCL/USCK/ADC4)PA4), ICSP.3
SINE_OUT: IC5.8 (OUT), IO_CON2.2, R40.2
SQR_OUT: IC5.1 (OUT), IO_CON1.3, R22.1
SUB_SQR_OUT: IC5.7 (OUT), IO_CON1.2, R24.1
TRI_OUT: C15.1, IC7.7 (OUT), IO_CON2.4, R31.2, R42.1
VREF: IC1.6 (VREF), IC4.13 ((PCINT0/AREF/ADC0)PA0), R8.2, R10.2, TP2.1, VR1.C

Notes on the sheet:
Adjust VREF_SET pot to get 4.00V @ TP2
Adjust CV_OFFSET pot to get a offset of -1.50V @ TP1

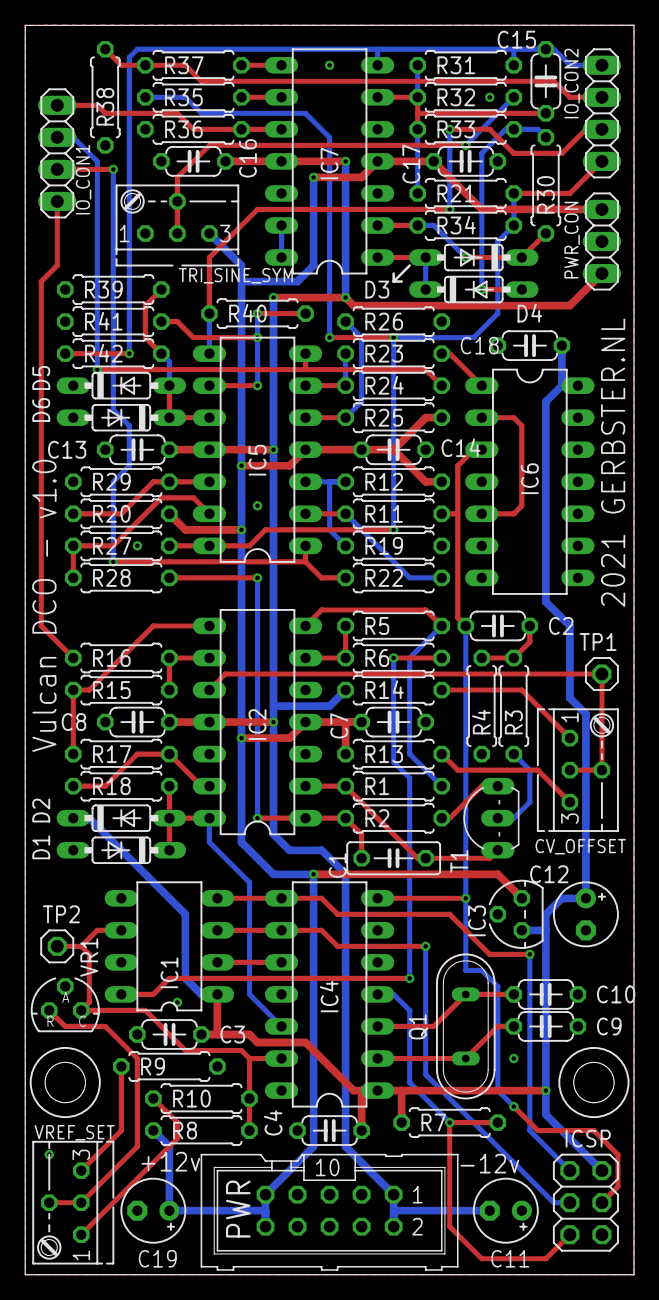
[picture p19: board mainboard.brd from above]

Board: 2 copper layers, 48.3 x 99.1 mm, 85 parts (0 on the bottom side), 56 nets.

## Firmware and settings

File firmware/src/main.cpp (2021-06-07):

#include <avr/io.h>
#include <avr/interrupt.h>
#include <avr/pgmspace.h>

// The TinySPI lib is used to communicate with the DAC
#include <tinySPI.h>  

// The frequency lookup table. For every value coming
// from the ADC (1024 in total), there is a corresponding 
// value to set the Frequency of the PWM using the ocr_step_value.
// These values are precalculated to improve speed.
#include <clock_frq_lookup.h>

// The DAC lookup table. For every value coming
// from the ADC (1024 in total), there is a corresponding 
// value to set the DAC to generate the Input Voltage.
// These values are precalculated to improve speed.
#include <dac_voltage_lookup.h>

// define the SPI latch pin
#define SPI_LATCH PA3

// function declarations
void setDACVoltage(uint16_t value);
uint16_t getADCSample(void);

// declare variable for ocr_step_value
// 45455 is just a default value
volatile uint16_t ocr_step_value = 5252; // 238hz

// declare variable for the unput_voltage read by the ADC
volatile uint16_t input_voltage = 0;
volatile uint16_t current_input_voltage = 0;

int main(void)
{
    /*
     * DAC Config
     */

    // set pin config
    DDRA |= (1 << SPI_LATCH);

    // start SPI library
    SPI.begin(); 

    // SPI_LATCH goes high 
    PORTA |= (1 << SPI_LATCH); 

    /*
     * Timer1 Config
     */

    // set pin to pwm output mode 
    DDRA |= (1 << DDA6); 

    // clear Timer1 Registers
    TCCR1A = 0;
    TCCR1B = 0;

    // enable 'Compare Match Toggle' on OC1A
    TCCR1A |= (1 << COM1A0);

    // set Prescaler to /8
    TCCR1B |= (1 << CS11)| (0 << CS10);

    // Output Compare Match A Interrupt Enable
    TIMSK1 |= (1 << OCIE1A);
    
    /*
     * ADC Config
     */

    // Set ADC prescaler to 128 - 125KHz sample rate @ 16MHz
    ADCSRA |= (1 << ADPS2) | (1 << ADPS1) | (1 << ADPS0);
  
    // set ADC1 as the input channel and enable external voltage reference (4.0V)
    ADMUX |= (1 << MUX0) | (1 << REFS0);

    // Set ADC to Free-Running Mode
    ADCSRA |= (1 << ADATE);  
    
    // Enable ADC
    ADCSRA |= (1 << ADEN);

    // Enable ADC Interrupt
    ADCSRA |= (1 << ADIE);  

    // Enable Global Interrupts
    sei(); 

    // Start A2D Conversions    
    ADCSRA |= (1 << ADSC);  

    //setDACVoltage(80);

    // Loop Forever
    for(;;)  
	{
	}  
}

/*
 * setDACVoltage
 */
void setDACVoltage(uint16_t value)
{
    // Set the config bits
    uint8_t config_bits = 0 << 3 | 0 << 2 | 1 << 1 | 1;

    // Compose the first byte to send to the DAC:
    // the 4 control bits, and the 4 most significant bits of the value
    uint8_t first_byte = config_bits << 4 | (value & 0xF00) >> 8;

    // Second byte is the lower 8 bits of the value
    uint8_t second_byte = value & 0xFF;

    // SPI_LATCH goes low
    PORTA &= ~(1 << SPI_LATCH); 

    SPI.transfer(first_byte);
    SPI.transfer(second_byte); 

    // SPI_LATCH goes high 
    PORTA |= (1 << SPI_LATCH); 
}

/*
 * The interrupt handler for the ADC 
 */
ISR(ADC_vect)
{
    // get the sample value from ADCL
    uint8_t adc_lobyte = ADCL;

    // add lobyte and hibyte to combine new input_voltage
    input_voltage = ADCH << 8 | adc_lobyte;

    if(input_voltage != current_input_voltage)
    {
        // set the Freqency
        // use pgm_read_word_near to get the value from flash memory
        ocr_step_value = pgm_read_word_near(frq_lookup + input_voltage);       

        // set the DAC
        // use pgm_read_word_near to get the value from flash memory
        setDACVoltage(pgm_read_word_near(dac_lookup + input_voltage));

        // store the new into the current
        current_input_voltage = input_voltage;
    }
}

/*
 * The interrupt handler for Timer1 
 */
ISR(TIM1_COMPA_vect) 
{
    // By continually adding a value to the OCR1A value we can
    // create a PWM signal with a variable Frequency which is
    // not bound by the prescaler and has a 50% duty cycle.
    OCR1A = OCR1A + ocr_step_value;
}

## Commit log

2021-05-21 add firmware files
    [mainboard.brd, mainboard.sch]
2021-06-07 Updated Schematics & Firmware
    [ioboard.brd, ioboard.sch, mainboard.brd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]
2021-06-07 added schematic PDF's
2021-06-15 Updated Schematics, Fixed Power Socket orientation
    [Vulcan-DCO-ioboard.GBL, Vulcan-DCO-ioboard.GBO, Vulcan-DCO-ioboard.GBP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]
2021-07-19 Fixed minor issues, added documentation and updated some faceplates
    [ioboard.brd, ioboard.dxf, mainboard.sch]
2021-08-06 Updated some schematics and docs
    [Vulcan-DCO-ioboard.GBL, Vulcan-DCO-ioboard.GBO, Vulcan-DCO-ioboard.GBP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]
2021-08-10 Fixed some bugs and updated documentation
    [Vulcan-DCO-ioboard.XLN, Vulcan-DCO-mainboard.XLN, gerber_job.gbrjob]
2021-09-26 re added files
    [Vulcan-DCO-ioboard.GBL, Vulcan-DCO-ioboard.GBO, Vulcan-DCO-ioboard.GBP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]
2022-04-20 Some updates & bugfixes
    [Vulcan-DCO-ioboard.XLN, Vulcan-DCO-mainboard.XLN, gerber_job.gbrjob]
2022-04-22 Fixed schematics & descriptions
    [Vulcan-DCO-ioboard.XLN, Vulcan-DCO-mainboard.XLN, gerber_job.gbrjob]
2022-05-17 Updated Firmware
    [Vulcan-DCO-ioboard.XLN, Vulcan-DCO-mainboard.XLN, gerber_job.gbrjob]
2022-05-18 Updated Faceplates
    [Vulcan-DCO-ioboard.XLN, Vulcan-DCO-mainboard.XLN, gerber_job.gbrjob]
2022-05-18 Fixed issues
    [Vulcan-DCO-ioboard.XLN, Vulcan-DCO-mainboard.XLN, gerber_job.gbrjob]
2022-05-21 Fixed schematics
    [Vulcan-DCO-ioboard.XLN, Vulcan-DCO-mainboard.XLN, gerber_job.gbrjob]
2022-05-28 General updates
    [Vulcan-DCO-ioboard.GKO, Vulcan-DCO-mainboard.GKO, copper_bottom.gbr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]
2022-06-13 Faceplates & Bugfixes
    [drills.xln, gerber_job.gbrjob]
2023-01-06 added firmware hex files
    [drills.xln, gerber_job.gbrjob]
